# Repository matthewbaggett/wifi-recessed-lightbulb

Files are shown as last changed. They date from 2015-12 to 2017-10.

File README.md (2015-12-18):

# WifiLight MR16 Mk8

Its very easy to get hold of a wifi-controlled lightbulb that plugs into an Edison Screw (E27) fitting or a Bayonette fitting (B22).. It is possible to get some IR remote controlled GU10 light fittings.. But what about an ESP8266-powered wifi-enabled light fitting to go into an MR16 socket?

With this in mind I have set out to develop such a product.

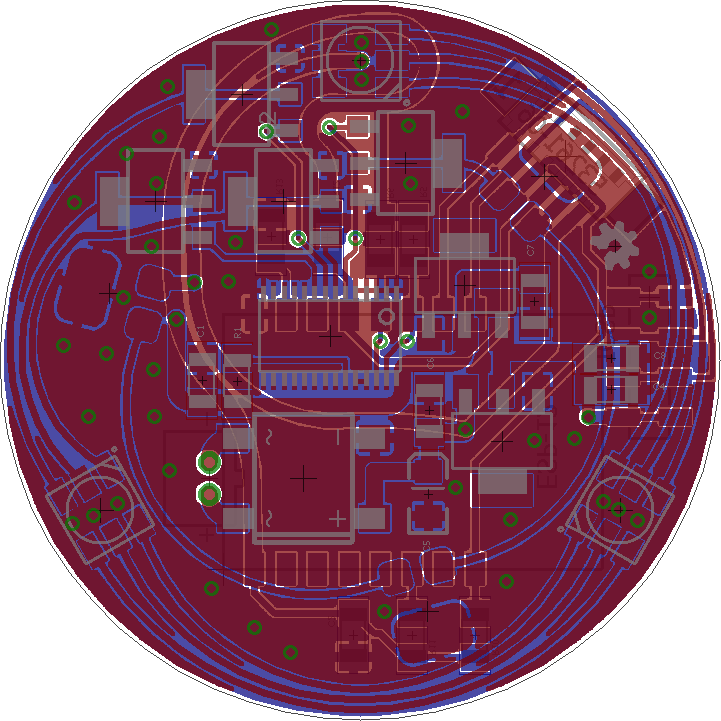
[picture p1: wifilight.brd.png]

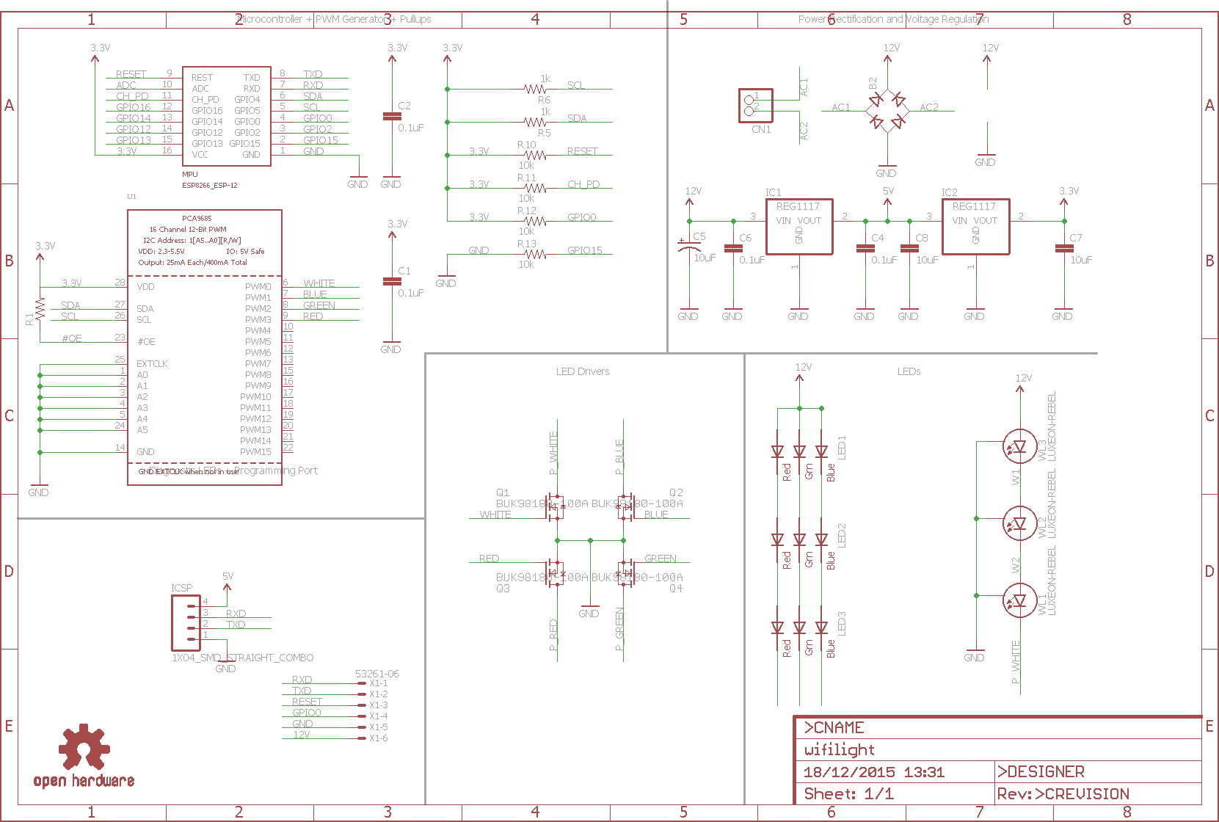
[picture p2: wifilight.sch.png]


# Programming Harness

To make it easy to program the ESP9266 via the 1.5mm JST socket, I designed a FTDI-based programmer. I have also attached a SMD 6 pin header that works just like any other FTDI serial USB device to make it useful beyond the life of this project.

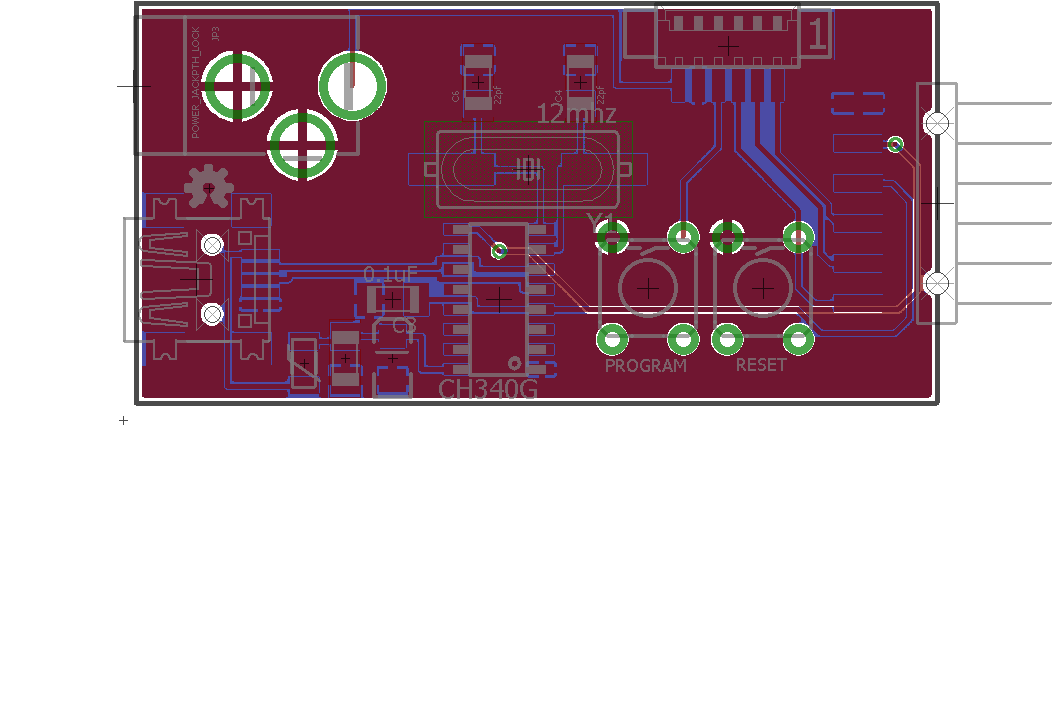
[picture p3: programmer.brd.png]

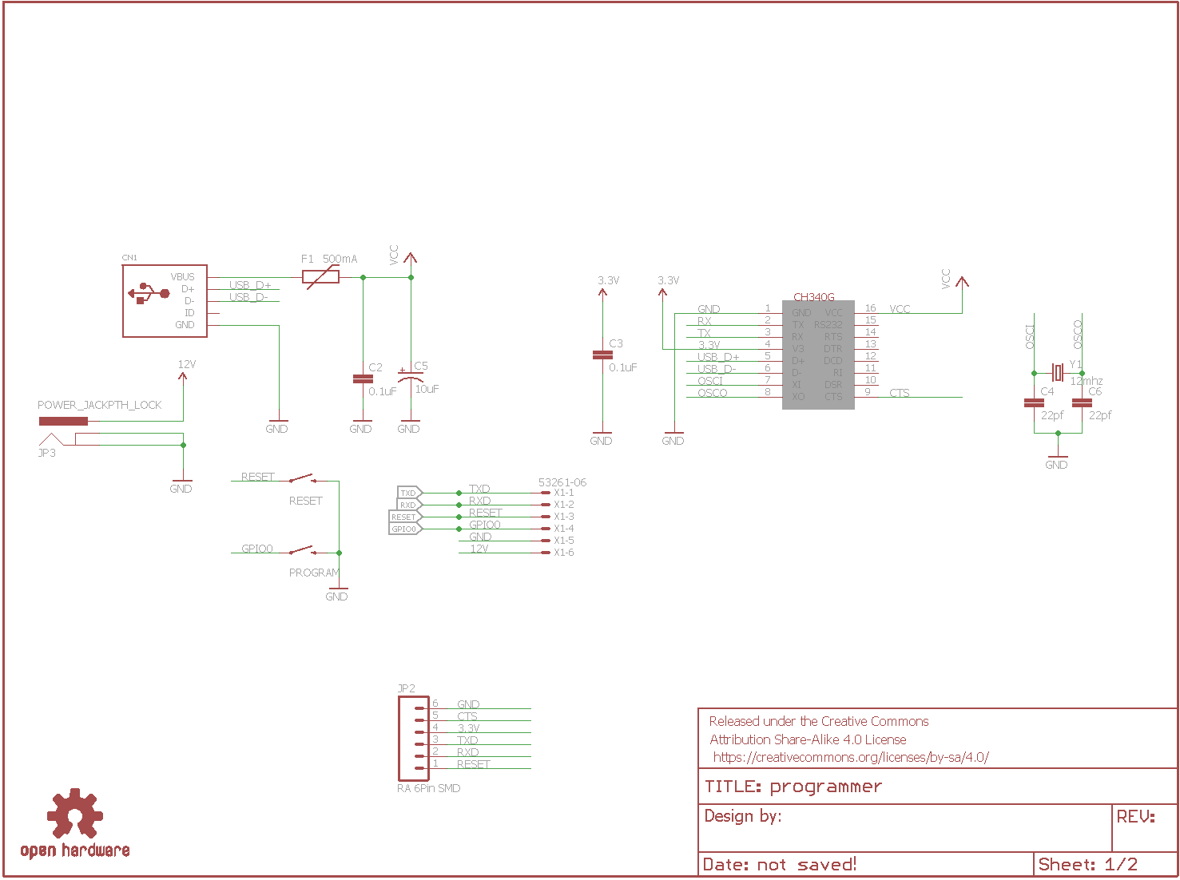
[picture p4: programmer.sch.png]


# Licence

<br />This work is licensed under a <a rel="license" href="http://creativecommons.org/licenses/by-nc/4.0/">Creative Commons Attribution-NonCommercial 4.0 International License</a>.

May be re-licenced on request.

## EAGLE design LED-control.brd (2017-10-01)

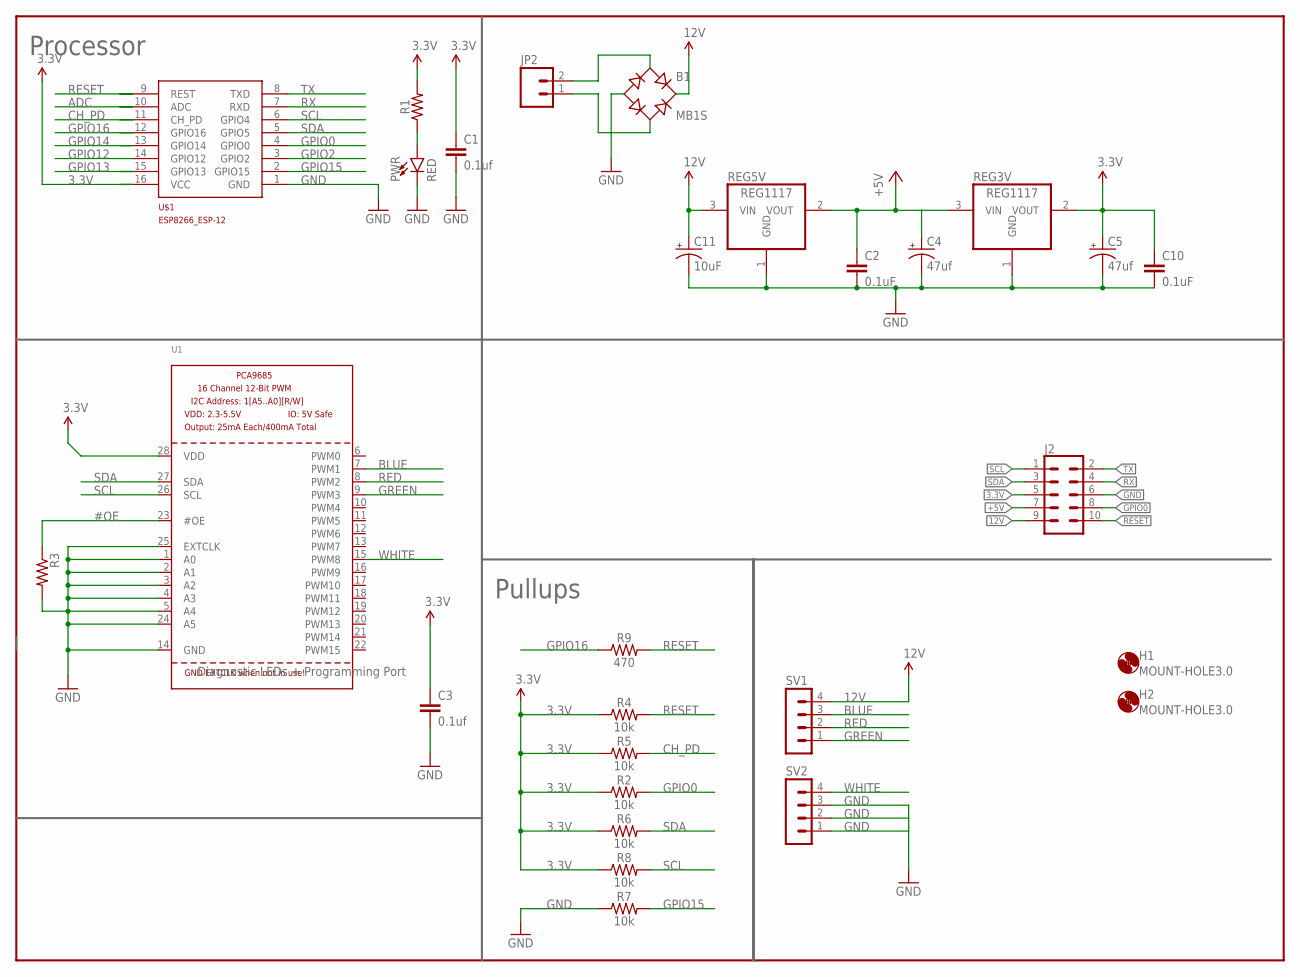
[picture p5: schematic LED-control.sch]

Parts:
B1: MB1S; SOIC-4
C1, C3: 0.1uf; C1206
C2, C10: 0.1uF; C1206
C4, C5: 47uf; PANASONIC_C
C11: 10uF; EIA3216
FRAME1: FRAME-LETTERNO_PACKAGE; DUMMY
H1, H2: MOUNT-HOLE3.0; 3,0
J2: CONN_05X2SHD; 2X5-SHROUDED
JP2: M02JST-PTH-VERT; JST-2-PTH-VERT
PWR: RED; LED-1206
R1: 1206
R2, R4, R5, R6, R7, R8: 10k; 1206
R3: R1206
R9: 470; 1206
REG3V, REG5V: REG1117; SOT223
SV1, SV2: MA04-1
U1: PCA9685; TSSOP28
U$1: ESP8266_ESP-12; ESP8266-ESP12

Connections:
3.3V: C1.1, C3.1, C5.+, C10.1, J2.5, R1.2, R2.1, R4.1, R5.1, R6.1, R8.1, REG3V.2 (VOUT), U1.28 (VDD), U$1.16 (VCC)
12V: B1.+, C11.A (+), J2.9, REG5V.3 (VIN), SV1.4
#OE: R3.1, U1.23 (#OE)
+5V: C2.1, C4.+, J2.7, REG3V.3 (VIN), REG5V.2 (VOUT)
ADC: U$1.10 (ADC)
BLUE: SV1.3, U1.7 (PWM1)
CH_PD: R5.2, U$1.11 (CH_PD)
GND: B1.-, C1.2, C2.2, C3.2, C4.-, C5.-, C10.2, C11.C (-), J2.6, PWR.C, R3.2, R7.1, REG3V.1 (GND), REG5V.1 (GND), SV2.1, SV2.2, SV2.3, U1.1 (A0), U1.2 (A1), U1.3 (A2), U1.4 (A3), U1.5 (A4), U1.14 (GND), U1.24 (A5), U1.25 (EXTCLK), U$1.1 (GND)
GPIO0: J2.8, R2.2, U$1.4 (GPIO0)
GPIO2: U$1.3 (GPIO2)
GPIO12: U$1.14 (GPIO12)
GPIO13: U$1.15 (GPIO13)
GPIO14: U$1.13 (GPIO14)
GPIO15: R7.2, U$1.2 (GPIO15)
GPIO16: R9.1, U$1.12 (GPIO16)
GREEN: SV1.1, U1.9 (PWM3)
unnamed: PWR.A, R1.1
unnamed: B1.~1 (AC1), JP2.2
unnamed: B1.~2 (AC2), JP2.1
RED: SV1.2, U1.8 (PWM2)
RESET: J2.10, R4.2, R9.2, U$1.9 (REST)
RX: J2.4, U$1.7 (RXD)
SCL: J2.1, R8.2, U1.26 (SCL), U$1.6 (GPIO4)
SDA: J2.3, R6.2, U1.27 (SDA), U$1.5 (GPIO5)
TX: J2.2, U$1.8 (TXD)
WHITE: SV2.4, U1.15 (PWM8)

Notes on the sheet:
Processor
Pullups
Diagnostic LEDs + Programming Port

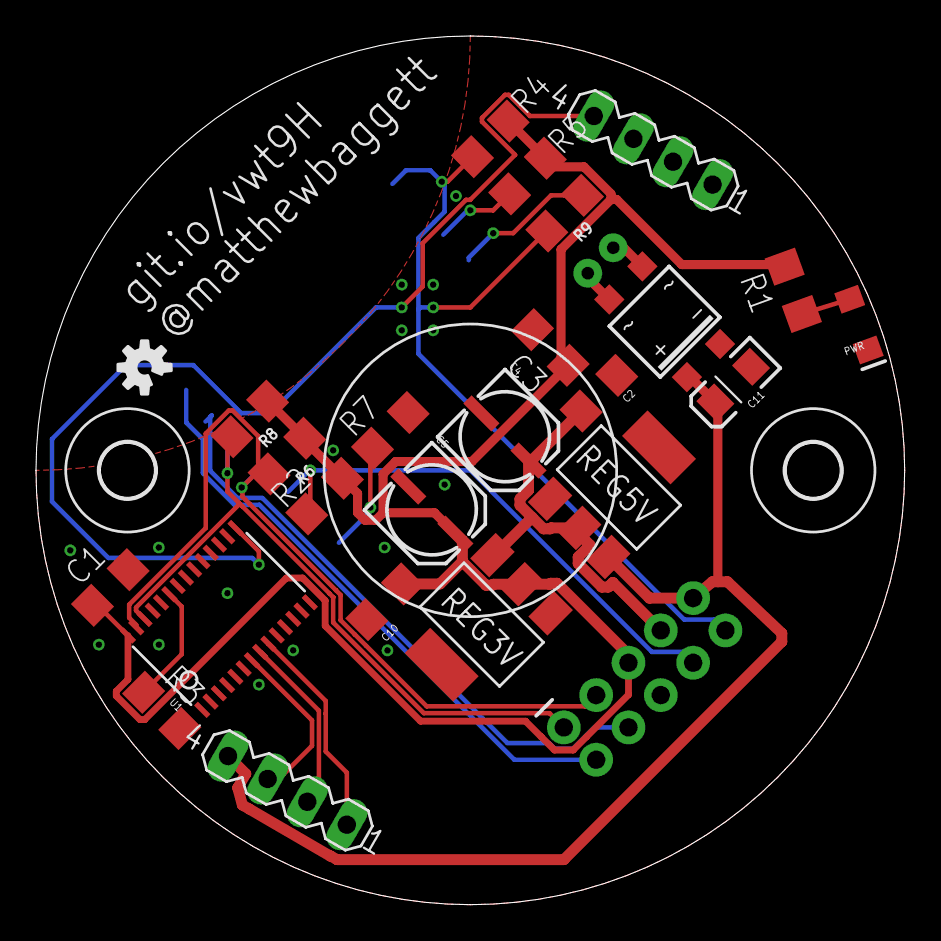
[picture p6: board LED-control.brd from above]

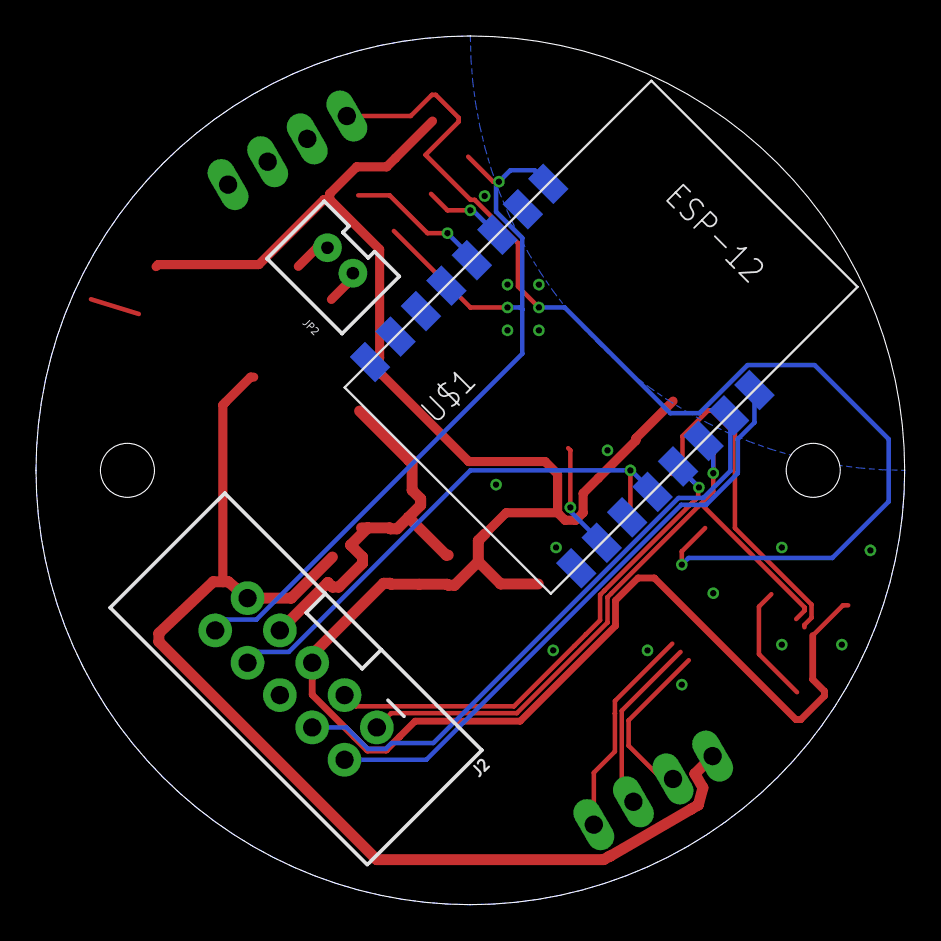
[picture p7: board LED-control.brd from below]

Board: 2 copper layers, 48.3 x 48.3 mm, 30 parts (3 on the bottom side), 21 nets.

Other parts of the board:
LOGO3: OSHW-LOGOS; OSHW-LOGO-S

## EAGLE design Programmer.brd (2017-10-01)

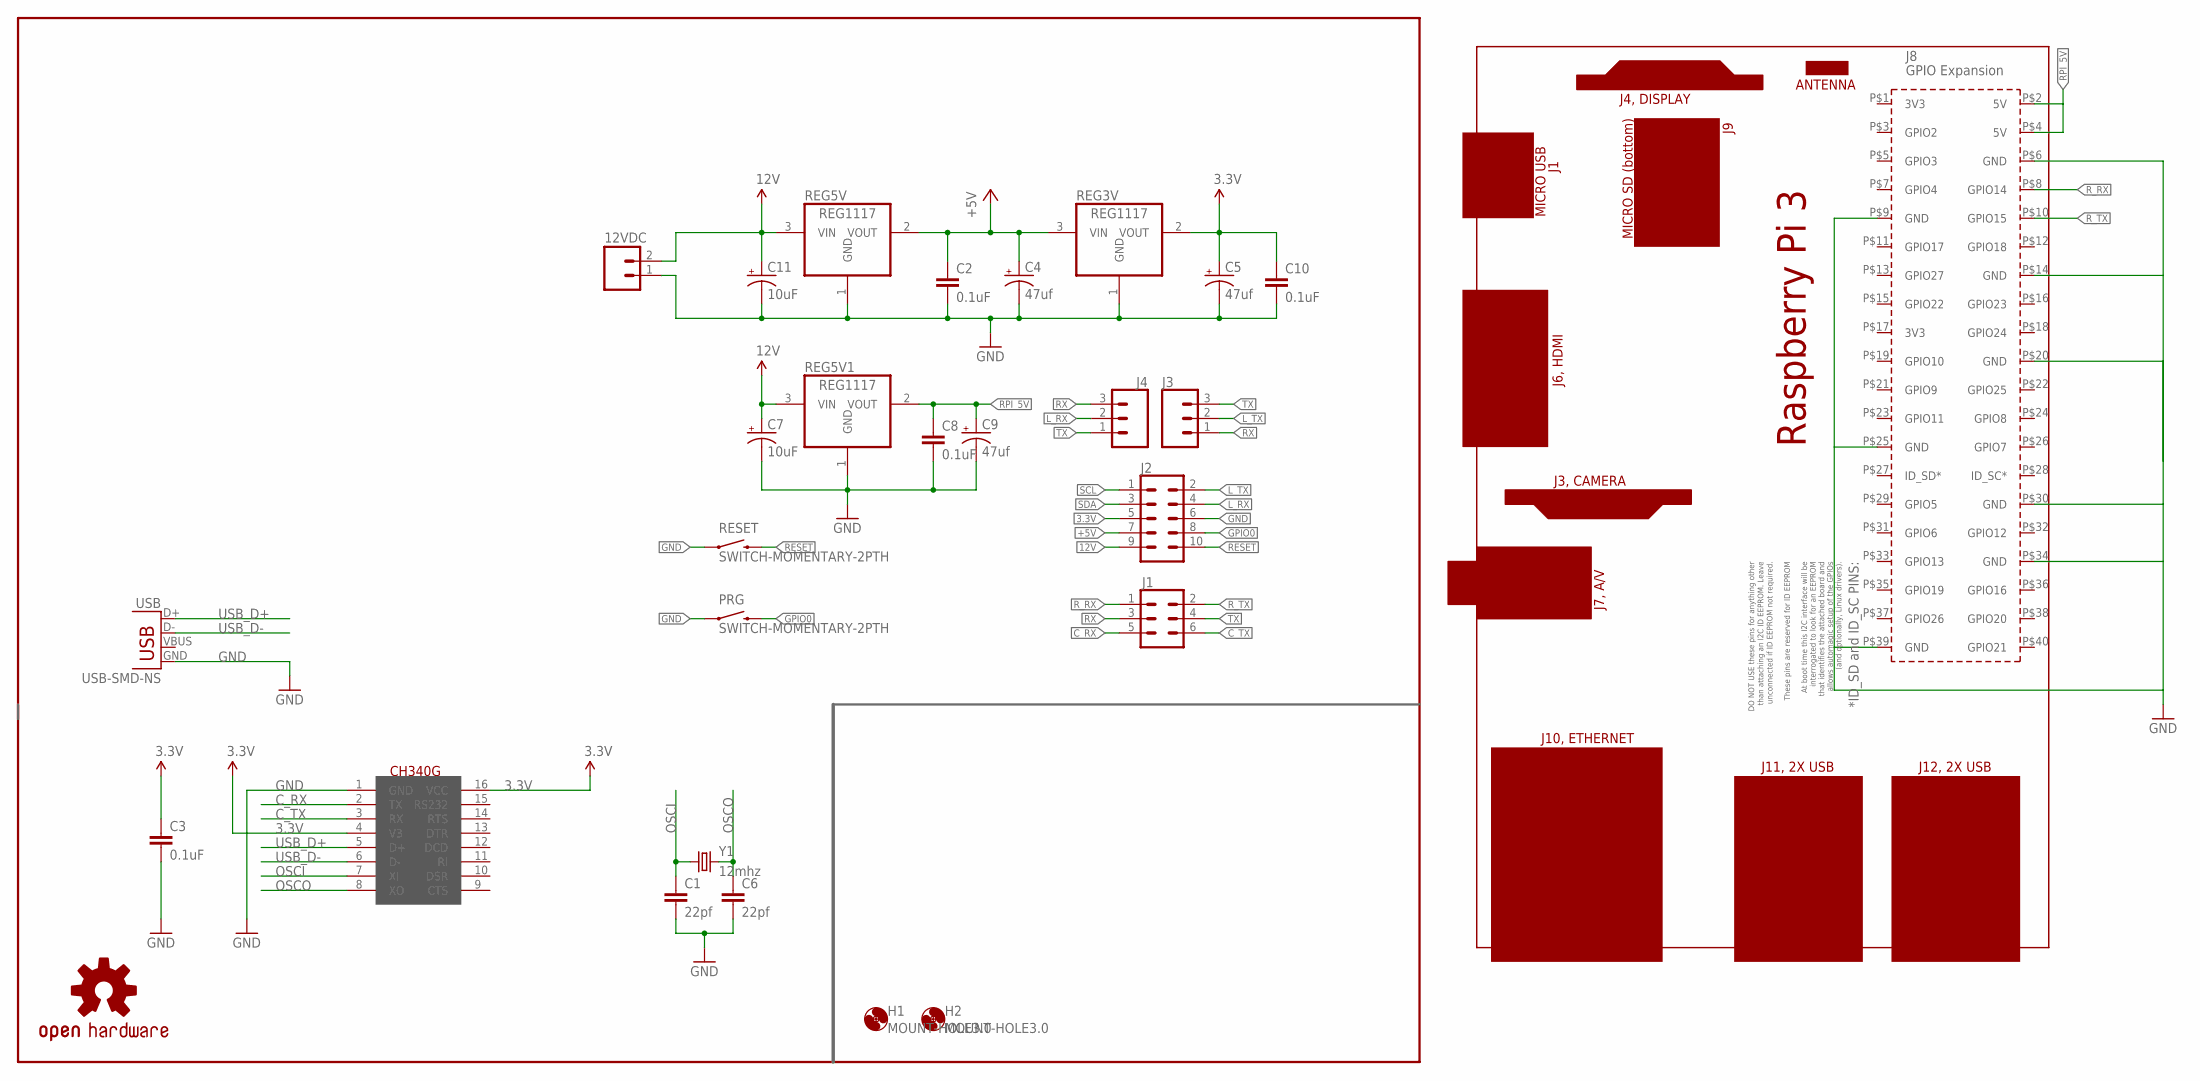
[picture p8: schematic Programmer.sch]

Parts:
12VDC: M023.5MM; SCREWTERMINAL-3.5MM-2
C1, C6: 22pf; 1206
C2, C8, C10: 0.1uF; 0603-CAP
C3: 0.1uF; C1206K
C4, C5, C9: 47uf; PANASONIC_C
C7, C11: 10uF; EIA3216
FRAME1: FRAME-LETTERNO_PACKAGE; DUMMY
H1, H2: MOUNT-HOLE3.0; 3,0
J1: CONN_03X22X3_SILK_MALE_PTH; 2X3
J2: CONN_05X2SHD; 2X5-SHROUDED
J3, J4: CONN_03LOCK; 1X03_LOCK
LOGO2: OSHW-LOGOS; OSHW-LOGO-S
PCB1: RPI3
PRG: SWITCH-MOMENTARY-2PTH; TACTILE-PTH
REG3V, REG5V, REG5V1: REG1117; SOT223
RESET: SWITCH-MOMENTARY-2PTH; TACTILE-PTH
U$2: CH340G; SOIC16
USB: USB-SMD-NS; USB-MINIB-NOSTOP
Y1: 12mhz; HC49UP

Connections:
3.3V: C3.1, C5.+, C10.1, J2.5, REG3V.2 (VOUT), U$2.4 (V3), U$2.16 (VCC)
12V: 12VDC.2, C7.A (+), C11.A (+), J2.9, REG5V.3 (VIN), REG5V1.3 (VIN)
+5V: C2.1, C4.+, J2.7, REG3V.3 (VIN), REG5V.2 (VOUT)
C_RX: J1.5, U$2.2 (TX)
C_TX: J1.6, U$2.3 (RX)
GND: 12VDC.1, C1.2, C2.2, C3.2, C4.-, C5.-, C6.2, C7.C (-), C8.2, C9.-, C10.2, C11.C (-), J2.6, PCB1.P$6 (GND), PCB1.P$9 (GND), PCB1.P$14 (GND), PCB1.P$20 (GND), PCB1.P$25 (GND), PCB1.P$30 (GND), PCB1.P$34 (GND), PCB1.P$39 (GND), PRG.1, REG3V.1 (GND), REG5V.1 (GND), REG5V1.1 (GND), RESET.1, U$2.1 (GND), USB.GND
GPIO0: J2.8, PRG.3 (2)
L_RX: J2.4, J4.2
L_TX: J2.2, J3.2
OSCI: C1.1, U$2.7 (XI), Y1.1
OSCO: C6.1, U$2.8 (XO), Y1.2
RESET: J2.10, RESET.3 (2)
RPI_5V: C8.1, C9.+, PCB1.P$2 (5V), PCB1.P$4 (5V), REG5V1.2 (VOUT)
RX: J1.3, J3.1, J4.3
R_RX: J1.1, PCB1.P$8 (GPIO14)
R_TX: J1.2, PCB1.P$10 (GPIO15)
SCL: J2.1
SDA: J2.3
TX: J1.4, J3.3, J4.1
USB_D+: U$2.5 (D+), USB.D+
USB_D-: U$2.6 (D-), USB.D-

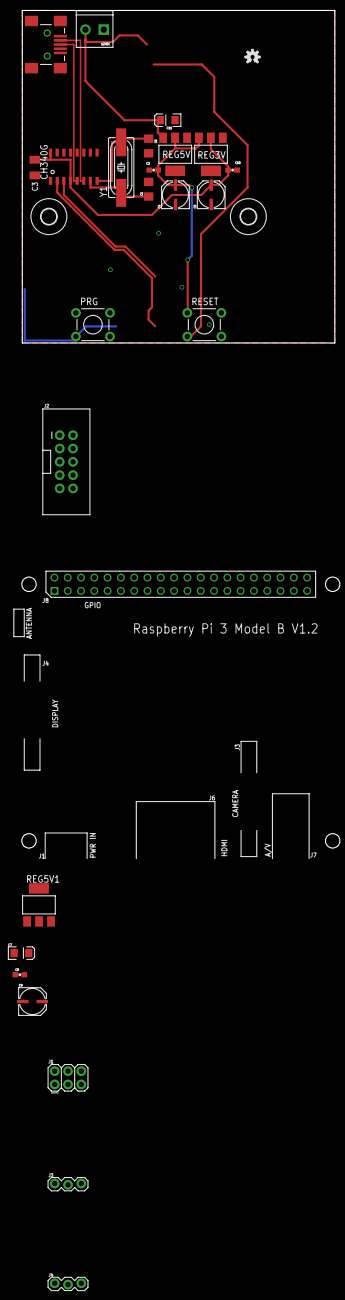
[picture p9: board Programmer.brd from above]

Board: 2 copper layers, 59.7 x 63.5 mm, 29 parts (0 on the bottom side), 19 nets.

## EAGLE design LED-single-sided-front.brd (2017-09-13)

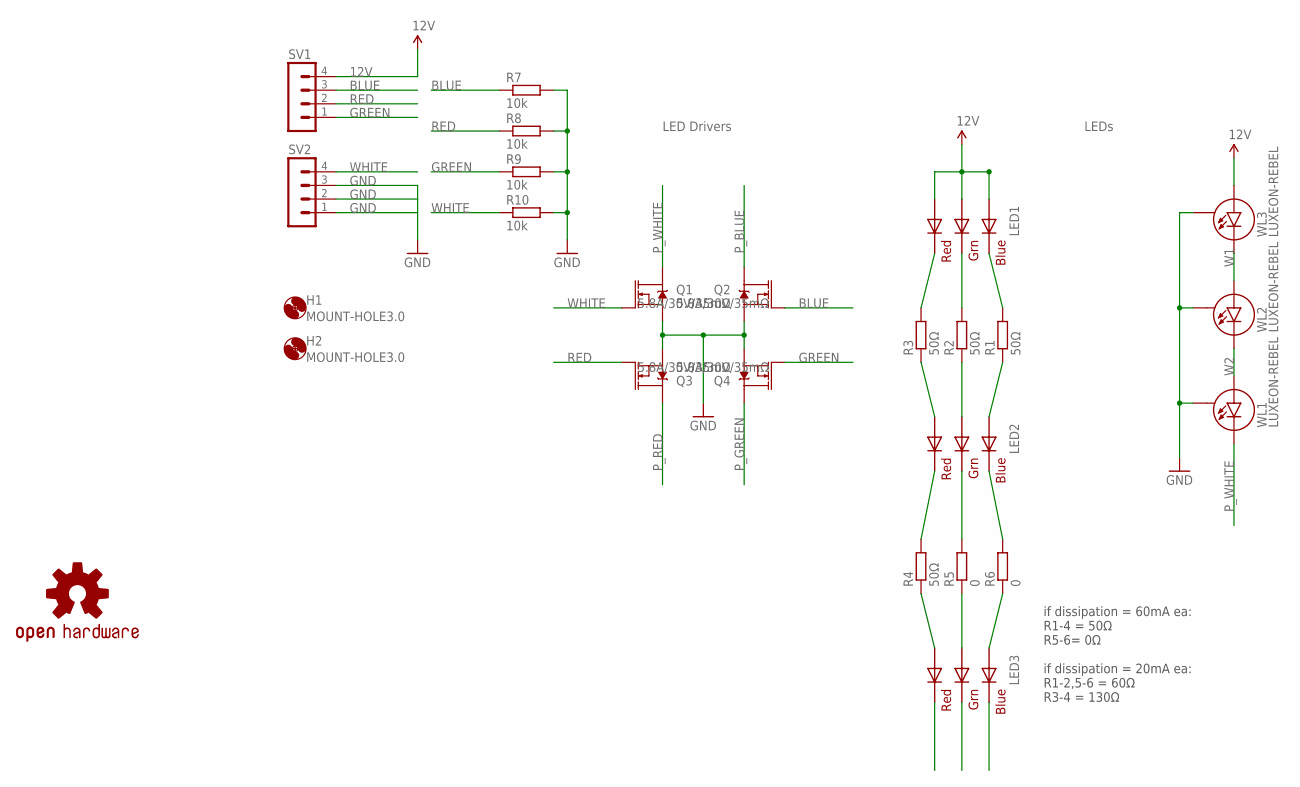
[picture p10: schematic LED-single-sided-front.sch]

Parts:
H1, H2: MOUNT-HOLE3.0; 3,0
LED1, LED2, LED3: RGBLED5050
LOGO1: OSHW-LOGOS; OSHW-LOGO-S
Q1, Q2, Q3, Q4: 5.8A/30V/35mΩ; SOT23-3
R1, R2, R3, R4: 50Ω; R1206
R5, R6: 0; R1206
R7, R8, R9, R10: 10k; R1206
SV1, SV2: MA04-1
WL1, WL2, WL3: LUXEON-REBEL

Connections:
12V: LED1.1 (GREEN_A), LED1.2 (RED_A), LED1.3 (BLUE_A), SV1.4, WL3.ANODE (A)
BLUE: Q2.1 (G), R7.1, SV1.3
GND: Q1.2 (S), Q2.2 (S), Q3.2 (S), Q4.2 (S), R7.2, R8.2, R9.2, R10.2, SV2.1, SV2.2, SV2.3, WL1.P$3 (S), WL2.P$3 (S), WL3.P$3 (S)
GREEN: Q4.1 (G), R9.1, SV1.1
unnamed: LED1.5 (RED_C), R3.2
unnamed: LED1.6 (GREEN_C), R2.2
unnamed: LED1.4 (BLUE_C), R1.2
unnamed: LED3.2 (RED_A), R4.1
unnamed: LED3.1 (GREEN_A), R5.1
unnamed: LED3.3 (BLUE_A), R6.1
unnamed: LED2.5 (RED_C), R4.2
unnamed: LED2.6 (GREEN_C), R5.2
unnamed: LED2.4 (BLUE_C), R6.2
unnamed: LED2.2 (RED_A), R3.1
unnamed: LED2.1 (GREEN_A), R2.1
unnamed: LED2.3 (BLUE_A), R1.1
P_BLUE: LED3.4 (BLUE_C), Q2.3 (D)
P_GREEN: LED3.6 (GREEN_C), Q4.3 (D)
P_RED: LED3.5 (RED_C), Q3.3 (D)
P_WHITE: Q1.3 (D), WL1.CATHODE (C)
RED: Q3.1 (G), R8.1, SV1.2
W1: WL2.ANODE (A), WL3.CATHODE (C)
W2: WL1.ANODE (A), WL2.CATHODE (C)
WHITE: Q1.1 (G), R10.1, SV2.4

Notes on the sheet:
LEDs
LED Drivers
if dissipation = 60mA ea: R1-4 = 50Ω R5-6= 0Ω if dissipation = 20mA ea: R1-2,5-6 = 60Ω R3-4 = 130Ω

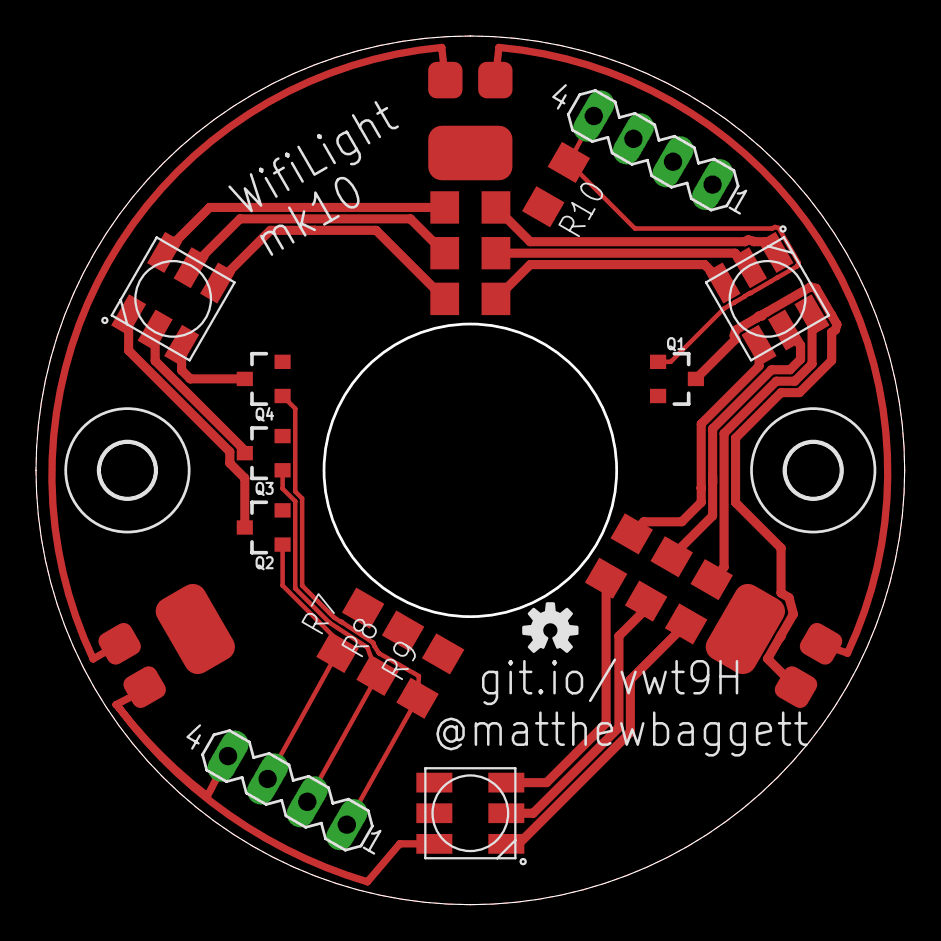
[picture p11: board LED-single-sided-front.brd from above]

Board: 2 copper layers, 48.3 x 48.3 mm, 25 parts (0 on the bottom side), 24 nets.

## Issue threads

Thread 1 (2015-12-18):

Mk8 Programmer - Redesign to put GPIO0 and RESET onto better pushswitches

matthewbaggett, 2015-12-18:
OMRON 10xxx series switch?

Closed 2015-12-18.

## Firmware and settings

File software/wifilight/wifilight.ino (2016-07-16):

#include <PCA9685.h>

#include <Wire.h>

#include <ESP8266WiFi.h>
#include <ESP8266WiFiMesh.h>

unsigned int request_i = 0;
unsigned int response_i = 0;

PCA9685 ledDriver; 

String manageRequest(String request);

/* Create the mesh node object */
ESP8266WiFiMesh mesh_node = ESP8266WiFiMesh(ESP.getChipId(), manageRequest);

/**
 * Callback for when other nodes send you data
 *
 * @request The string received from another node in the mesh
 * @returns The string to send back to the other node
 */
String manageRequest(String request)
{
  /* Print out received message */
  Serial.print("received: ");
  Serial.println(request);

  /* return a string to send back */
  char response[60];
  sprintf(response, "Hello world response #%d from Mesh_Node%d.", response_i++, ESP.getChipId());
  return response;
}


void setup()
{
  Serial.begin(115200);
  delay(2);

  Serial.println();
  Serial.println();
  Serial.println("Setting up i2c...");
  Wire.begin();
  ledDriver.begin(0);  // Address pins A5-A0 set to B111000
  if (ledDriver.init())  {
    Serial.println("Connected to PCA9865");
  } else {
    Serial.println("Failed to connect to PCA9865");
  }
  delay(2);

  int duty = 100;
  for(int led = 0; led < 16; led++){
    Serial.print("Setting LED #");
    Serial.print(led);
    Serial.print(" to ");
    Serial.print(duty);
    Serial.println("% duty");
    ledDriver.setLEDDimmed(led, duty);
  }
  Serial.println("Setting up mesh node...");

  /* Initialise the mesh node */
  mesh_node.begin();
}

void loop()
{
  /* Accept any incoming connections */
  mesh_node.acceptRequest();

  /* Scan for other nodes and send them a message */
  char request[60];
  sprintf(request, "Hello world request #%d from Mesh_Node%d.", request_i++, ESP.getChipId());
  mesh_node.attemptScan(request);
  delay(1000);
}

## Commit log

2015-07-26 Initial commit, DRC OK, lets see what oshpark make of it.
    [wifilight-leds-cheaper.brd, wifilight-leds-cheaper.sch]
2015-07-26 Damnit, how was I supposed to power this thing?
    [wifilight-leds-cheaper.brd, wifilight-leds-cheaper.sch]
2015-08-08 As ordered recently. Discovered that SOT-23's are puny and 4 Luxeon Rebels are overkill. And that Banggood has cheaper ESP8266 modules.
    [wifilight-leds-cheaper.brd, wifilight-leds-cheaper.sch, wifilight-leds-cheaper.xlsx]
2015-08-08 Add a second ground plane on the top surface, pump it full of vias to help add thermal mass and heat spreading
    [wifilight-leds-cheaper.brd]
2015-08-21 Adding pogopin contacts
    [wifilight-leds-cheaper.brd, wifilight-leds-cheaper.sch]
2015-08-21 Add ground probe tag, drill locating hole in board.
    [wifilight-leds-cheaper.brd, wifilight-leds-cheaper.sch]
2015-08-21 initial probe board
    [wifilights-probe-board.brd, wifilights-probe-board.sch]
2015-08-21 add SCL & SDA pins pogopins for programming
    [wifilight-leds-cheaper.brd, wifilight-leds-cheaper.sch]
2015-08-21 add TXD, RXD & GPIO0 pins pogopins for programming
    [wifilight-leds-cheaper.brd, wifilight-leds-cheaper.sch]
2015-08-21 add GPIO2 pins pogopins for programming
    [wifilight-leds-cheaper.brd, wifilight-leds-cheaper.sch]
2015-08-21 Probe board complete
    [wifilights-probe-board.brd, wifilights-probe-board.sch]
2015-08-21 Adding shim to hold PCB in place ontop of probe board
    [wifilights-shim.brd, wifilights-shim.sch]
2015-08-31 Swapped to using 12x Luxeon Rebels instead of the hard-to-solder consolidated package.
    [wifilight-leds-cheaper.brd, wifilight-leds-cheaper.sch]
2015-08-31 Fix some DRC issues
    [wifilight-leds-cheaper.brd]
2015-08-31 Shim made irrelevent
    [wifilights-shim.brd, wifilights-shim.sch]
2015-08-31 Better probe board
    [wifilights-probe-board.brd, wifilights-probe-board.sch]
2015-08-31 Removing labels of uselessness
    [wifilight-leds-cheaper.brd]
2015-09-04 Rotate socket to allow it not to clip through one of the SOT-223 transitors
    [wifilight-leds-cheaper.brd, wifilight-leds-cheaper.sch]
2015-10-05 Adding more signals to a better connector, moved THINKING LED to another GPIO due to conflict
    [wifilight-leds-cheaper.brd, wifilight-leds-cheaper.sch]
2015-10-07 Added 3x4 pin headers. Added 2x i2c JST connectors.
    [wifilight-leds-cheaper.brd, wifilight-leds-cheaper.sch]
2015-10-09 Mk6 complete & DRC'd
    [wifilight-leds-cheaper.brd, wifilight-leds-cheaper.sch, wifilights-probe-board.brd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]
2015-10-09 Laughably out of date
    [wifilight-leds-cheaper.xlsx]
2015-10-09 Renamed boards
    [programmer.brd, programmer.sch, wifilight.brd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]
2015-10-09 Made mofications to schematics for readability
    [programmer.brd, programmer.sch, wifilight.brd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]
2015-10-10 Revision of programmer board to include a SMD 6 pin FTDI header.
    [programmer.brd, programmer.sch]
2015-11-20 Revised to use larger regulators, Revised to use 4 layers
    [wifilight.brd, wifilight.sch]
2015-12-18 Mk8 gets its PCA9685 back, the older LED controller turned out to only have 2 channels of PWM available, which is insufficient. Respan this board with 3xRGB 5050's and 3xLuxeon rebels. reduced comple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
    [wifilight.brd, wifilight.sch]
2015-12-18 Add ICSP header. Resolves #5
    [wifilight.brd, wifilight.sch]
2015-12-18 Changed to CH340G + Crystal instead of FT232RL Resolves #4. Using 12 Volt Barrel Jack Resolves #3. Moved to Omron 10xxx switches instead of slider, Resolves #1
    [programmer.brd, programmer.sch]
2015-12-23 Move the power connector further away from the SOC
    [wifilight.brd]
2016-04-17 A fresh start
    [LED-control.brd, LED-control.sch, LED-single-sided-front.brd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]
2016-04-17 Revise all the things
    [LED-control.brd, LED-control.sch]
2016-04-17 mk9 brah.
    [LED-single-sided-front.brd, LED-single-sided-front.sch, Programmer.brd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]
2016-07-16 Turn into a single board for devkit
    [devkit.brd, devkit.sch]
2016-07-16 add label
    [devkit.brd]
2016-07-16 Initial firmware that scanned for a now defunct i2c device
2017-09-13 Put hole in middle of board (hurr durr donuts). Change to smaller mosfets. Add pulldown resistors.
    [LED-single-sided-front.brd, LED-single-sided-front.sch]
2017-09-13 Reworking board to standardise on 1206 caps and resistors. Moving caps into the center where they'll clip through the hole in the top board. Move power connector to rear (duh). Remove i2c connectors.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
    [LED-control.brd, LED-control.sch]
2017-09-14 Finalised board design
    [LED-control.brd, LED-control.sch]

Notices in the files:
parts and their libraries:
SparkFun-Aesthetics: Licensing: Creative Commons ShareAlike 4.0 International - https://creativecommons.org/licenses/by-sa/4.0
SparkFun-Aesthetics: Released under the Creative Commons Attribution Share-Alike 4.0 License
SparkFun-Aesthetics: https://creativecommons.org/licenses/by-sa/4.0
